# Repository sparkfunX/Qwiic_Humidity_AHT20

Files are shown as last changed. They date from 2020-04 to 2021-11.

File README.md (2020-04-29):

SparkFun Qwiic Humidity AHT20
=============================

Qwiic AHT20 (https://cdn.sparkfun.com/assets/parts/1/5/5/0/2/16618-Qwiic_Humidity_AHT20-01.jpg)

New from SparkX, the AHT20 breakout board. This low-cost IC triggers temperature and humidity measurements easily over the Qwiic bus you know and love.

SparkFun labored with love to design this board. Feel like supporting open-source hardware?
Buy a [board](https://www.sparkfun.com/) from SparkFun!

Repository Contents
-------------------

* **/Documents** - Datasheet for the AHT20 IC.
* **/Hardware** - Eagle design files (.brd, .sch).
* **/Production** - Production panel files (.brd).

License Information
-------------------

This product is _**open source**_!

Please review the LICENSE.md file for license information.

If you have any questions or concerns regarding our licensing, please contact technical support on our [SparkFun Forum](https://www.sparkfun.com/viewforum.php?f=152).

Distributed as-is; no warranty is given.

- Your friends at SparkFun

_<COLLABORATION CREDIT>_

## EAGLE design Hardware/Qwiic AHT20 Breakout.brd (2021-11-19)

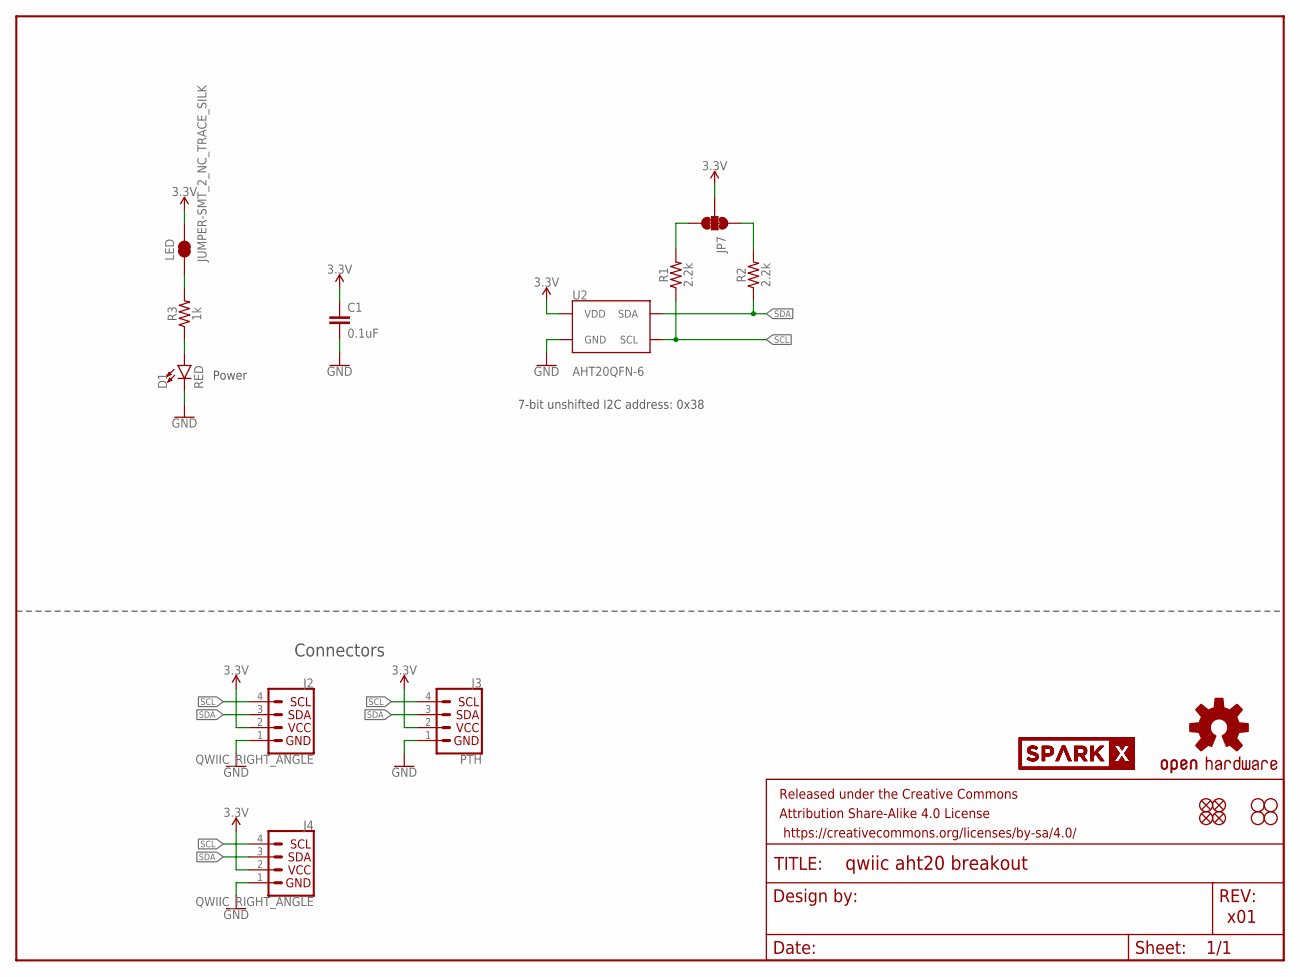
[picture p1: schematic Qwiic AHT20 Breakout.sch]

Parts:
C1: 0.1uF; 0603
D1: RED; LED-0603
FRAME1: FRAME-LETTER; CREATIVE_COMMONS
J2, J4: QWIIC_RIGHT_ANGLE; JST04_1MM_RA
J3: PTH; 1X04_NO_SILK
JP1, JP2, JP5, JP6: FIDUCIAL1X2; FIDUCIAL-1X2
JP3, JP4, JP8, JP9: STAND-OFF
JP7: JUMPER-SMT_3_2-NC_TRACE_SILK; SMT-JUMPER_3_2-NC_TRACE_SILK
LED: JUMPER-SMT_2_NC_TRACE_SILK; SMT-JUMPER_2_NC_TRACE_SILK
LOGO1: OSHW-LOGOMINI; OSHW-LOGO-MINI
R1, R2: 2.2k; 0603
R3: 1k; 0603
U2: AHT20QFN-6; QFN-6
U$1, U$2: SPARKX-LOGO4; SPARKX-MEDIUM

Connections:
3.3V: C1.1, J2.2, J3.2 (VCC), J4.2, JP7.2, LED.2, U2.VDD
GND: C1.2, D1.C, J2.1, J3.1 (GND), J4.1, U2.GND
unnamed: JP7.3, R1.2
unnamed: JP7.1, R2.2
unnamed: D1.A, R3.1
unnamed: LED.1, R3.2
SCL: J2.4, J3.4 (SCL), J4.4, R1.1, U2.SCL
SDA: J2.3, J3.3 (SDA), J4.3, R2.1, U2.SDA

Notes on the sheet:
x01
7-bit unshifted I2C address: 0x38
Power
Connectors

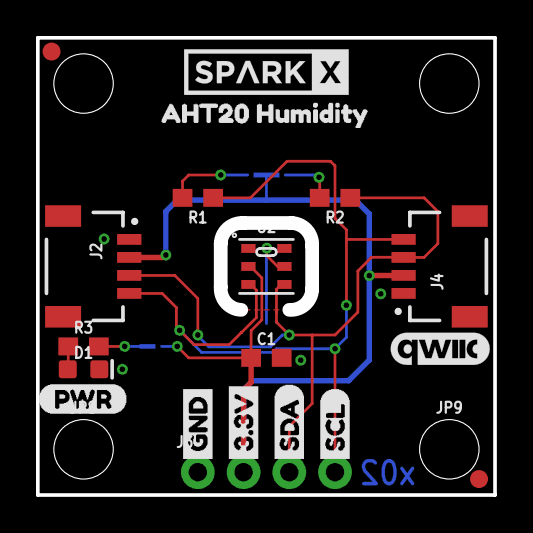
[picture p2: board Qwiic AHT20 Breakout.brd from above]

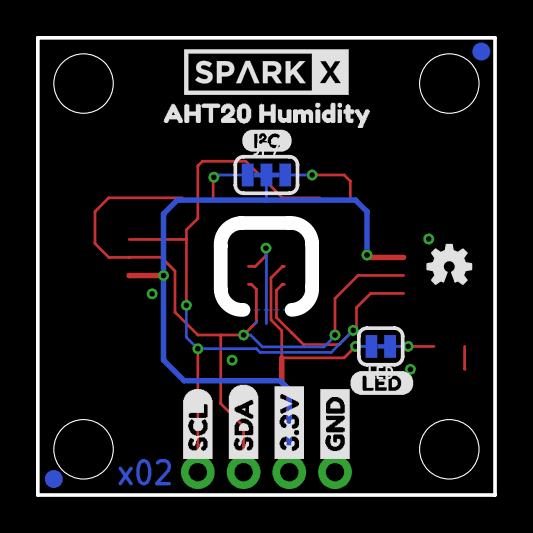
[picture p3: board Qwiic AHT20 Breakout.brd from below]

Board: 2 copper layers, 25.4 x 25.4 mm, 38 parts (13 on the bottom side), 8 nets.

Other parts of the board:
U$3, U$22: GND1
U$4, U$21: 3#3V2
U$5, U$27: SDA8
U$6, U$26: SCL9
U$8, U$14: AHT20_HUMIDITY2
U$9: I_SUPER2_C-()-03
U$10: (PWR)
U$11: QWIIC_5.5MM
U$12: LED_32
U$18: ORDERING_INSTRUCTIONS

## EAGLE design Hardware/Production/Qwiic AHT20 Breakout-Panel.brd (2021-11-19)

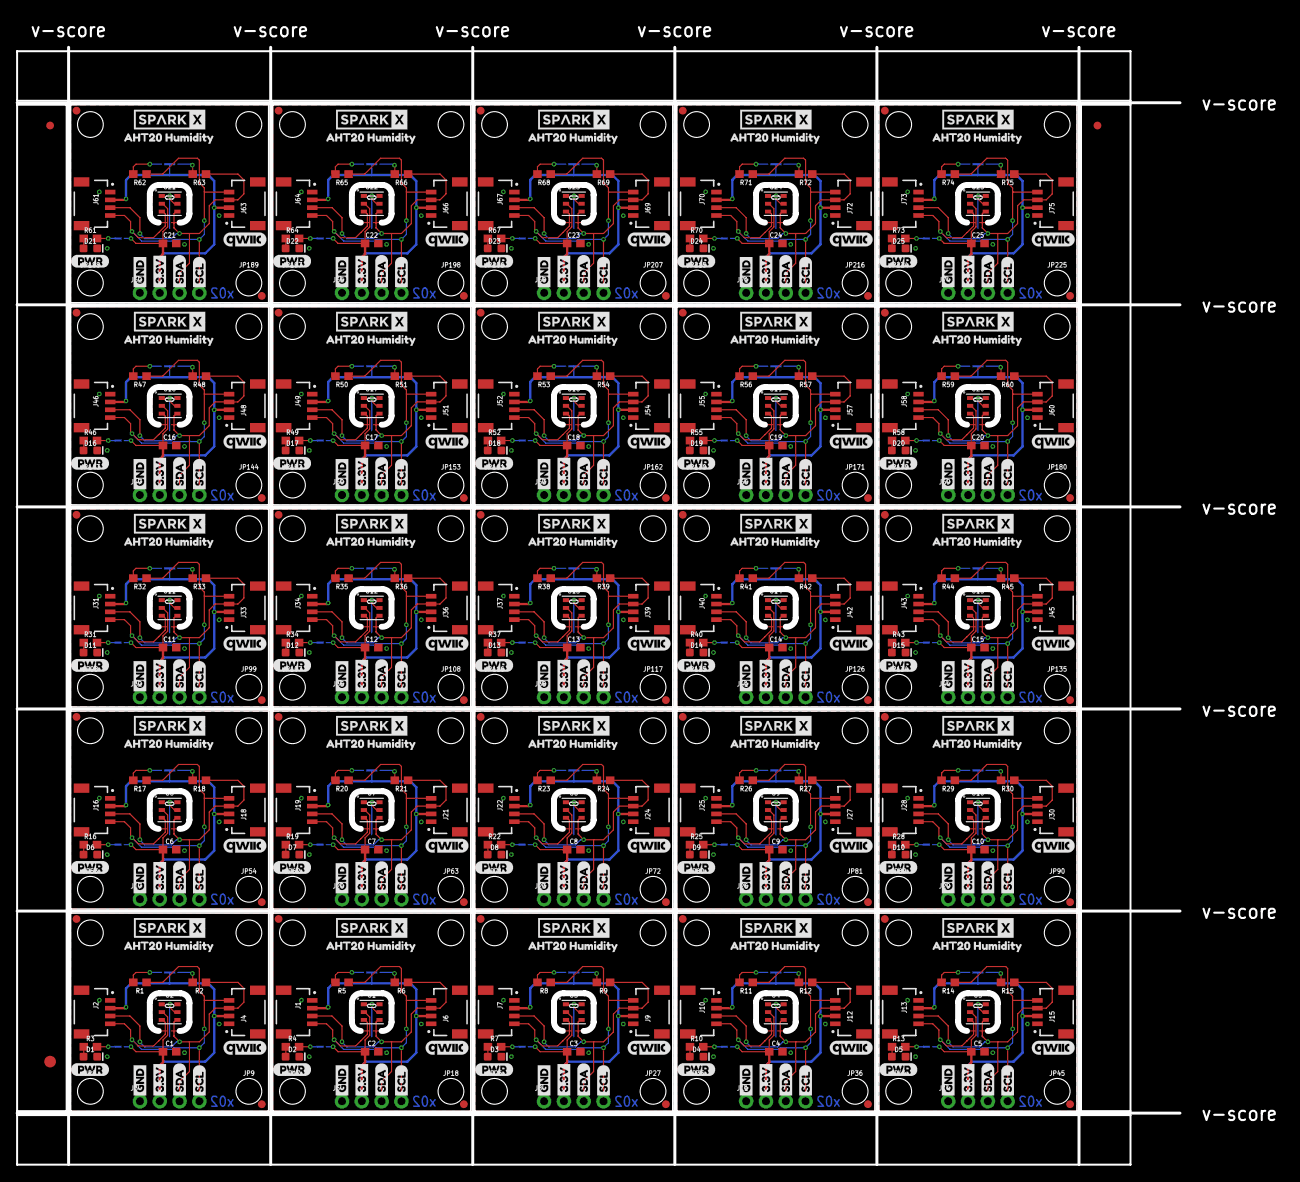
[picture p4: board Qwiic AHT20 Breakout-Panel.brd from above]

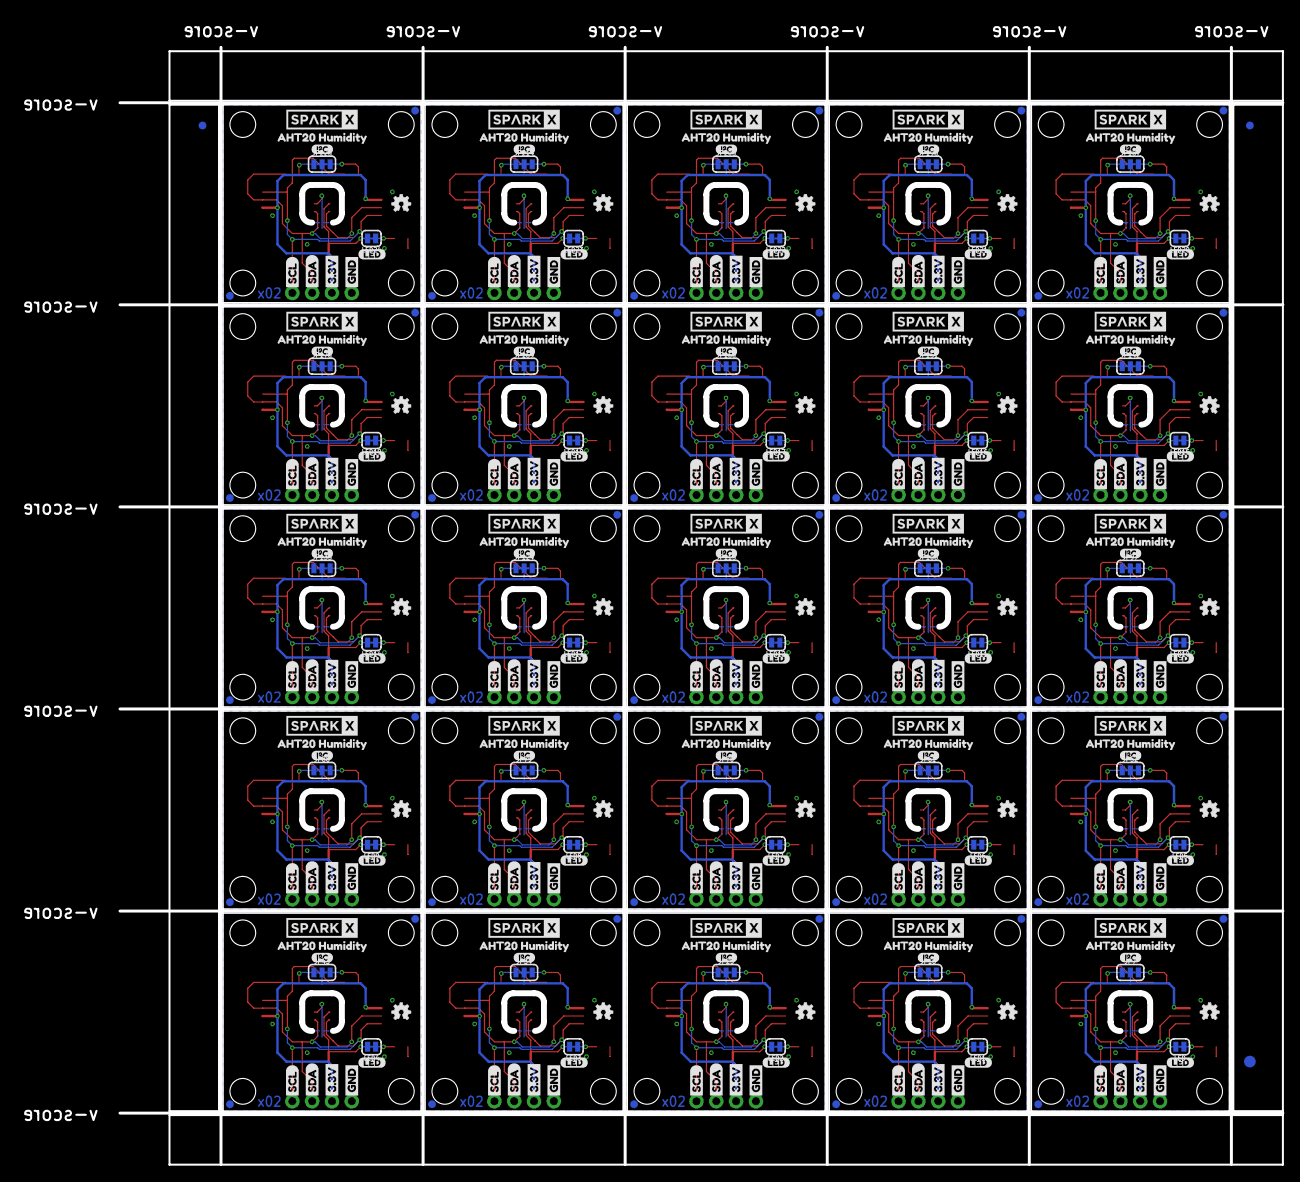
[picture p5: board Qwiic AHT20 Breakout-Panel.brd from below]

Board: 2 copper layers, 149.1 x 143.3 mm, 906 parts (328 on the bottom side), 200 nets.

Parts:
C1, C2, C3, C4, C5, C6, C7, C8, C9, C10, C11, C12, C13, C14, C15, C16, C17, C18, C19, C20, C21, C22, C23, C24, C25: 0.1uF; 0603
D1, D2, D3, D4, D5, D6, D7, D8, D9, D10, D11, D12, D13, D14, D15, D16, D17, D18, D19, D20, D21, D22, D23, D24, D25: RED; LED-0603
E$1, E$2, E$3, E$4: FIDUCIAL-1X2
E$5, E$6: FIDUCIAL-1.5X3
J1, J2, J4, J6, J7, J9, J10, J12, J13, J15, J16, J18, J19, J21, J22, J24, J25, J27, J28, J30, J31, J33, J34, J36, J37, J39, J40, J42, J43, J45, J46, J48, J49, J51, J52, J54, J55, J57, J58, J60, J61, J63, J64, J66, J67, J69, J70, J72, J73, J75: QWIIC_RIGHT_ANGLE; JST04_1MM_RA
J3, J5, J8, J11, J14, J17, J20, J23, J26, J29, J32, J35, J38, J41, J44, J47, J50, J53, J56, J59, J62, J65, J68, J71, J74: PTH; 1X04_NO_SILK
JP1, JP2, JP5, JP6, JP12, JP13, JP14, JP15, JP21, JP22, JP23, JP24, JP30, JP31, JP32, JP33, JP39, JP40, JP41, JP42, JP48, JP49, JP50, JP51, JP57, JP58, JP59, JP60, JP66, JP67, JP68, JP69, JP75, JP76, JP77, JP78, JP84, JP85, JP86, JP87, JP93, JP94, JP95, JP96, JP102, JP103, JP104, JP105, JP111, JP112, JP113, JP114, JP120, JP121, JP122, JP123, JP129, JP130, JP131, JP132, JP138, JP139, JP140, JP141, JP147, JP148, JP149, JP150, JP156, JP157, JP158, JP159, JP165, JP166, JP167, JP168, JP174, JP175, JP176, JP177, JP183, JP184, JP185, JP186, JP192, JP193, JP194, JP195, JP201, JP202, JP203, JP204, JP210, JP211, JP212, JP213, JP219, JP220, JP221, JP222: FIDUCIAL1X2; FIDUCIAL-1X2
JP3, JP4, JP8, JP9, JP10, JP11, JP17, JP18, JP19, JP20, JP26, JP27, JP28, JP29, JP35, JP36, JP37, JP38, JP44, JP45, JP46, JP47, JP53, JP54, JP55, JP56, JP62, JP63, JP64, JP65, JP71, JP72, JP73, JP74, JP80, JP81, JP82, JP83, JP89, JP90, JP91, JP92, JP98, JP99, JP100, JP101, JP107, JP108, JP109, JP110, JP116, JP117, JP118, JP119, JP125, JP126, JP127, JP128, JP134, JP135, JP136, JP137, JP143, JP144, JP145, JP146, JP152, JP153, JP154, JP155, JP161, JP162, JP163, JP164, JP170, JP171, JP172, JP173, JP179, JP180, JP181, JP182, JP188, JP189, JP190, JP191, JP197, JP198, JP199, JP200, JP206, JP207, JP208, JP209, JP215, JP216, JP217, JP218, JP224, JP225: STAND-OFF
JP7, JP16, JP25, JP34, JP43, JP52, JP61, JP70, JP79, JP88, JP97, JP106, JP115, JP124, JP133, JP142, JP151, JP160, JP169, JP178, JP187, JP196, JP205, JP214, JP223: JUMPER-SMT_3_2-NC_TRACE_SILK; SMT-JUMPER_3_2-NC_TRACE_SILK
LED, LED1, LED2, LED3, LED4, LED5, LED6, LED7, LED8, LED9, LED10, LED11, LED12, LED13, LED14, LED15, LED16, LED17, LED18, LED19, LED20, LED21, LED22, LED23, LED24: JUMPER-SMT_2_NC_TRACE_SILK; SMT-JUMPER_2_NC_TRACE_SILK
LOGO1, LOGO2, LOGO3, LOGO4, LOGO5, LOGO6, LOGO7, LOGO8, LOGO9, LOGO10, LOGO11, LOGO12, LOGO13, LOGO14, LOGO15, LOGO16, LOGO17, LOGO18, LOGO19, LOGO20, LOGO21, LOGO22, LOGO23, LOGO24, LOGO25: OSHW-LOGOMINI; OSHW-LOGO-MINI
R1, R2, R5, R6, R8, R9, R11, R12, R14, R15, R17, R18, R20, R21, R23, R24, R26, R27, R29, R30, R32, R33, R35, R36, R38, R39, R41, R42, R44, R45, R47, R48, R50, R51, R53, R54, R56, R57, R59, R60, R62, R63, R65, R66, R68, R69, R71, R72, R74, R75: 2.2k; 0603
R3, R4, R7, R10, R13, R16, R19, R22, R25, R28, R31, R34, R37, R40, R43, R46, R49, R52, R55, R58, R61, R64, R67, R70, R73: 1k; 0603
U1, U2, U3, U4, U5, U6, U7, U8, U9, U10, U11, U12, U13, U14, U15, U16, U17, U18, U19, U20, U21, U22, U23, U24, U25: AHT20QFN-6; QFN-6
U$1, U$2, U$7, U$13, U$33, U$34, U$49, U$50, U$65, U$66, U$81, U$82, U$97, U$98, U$113, U$114, U$129, U$130, U$145, U$146, U$161, U$162, U$177, U$178, U$193, U$194, U$209, U$210, U$225, U$226, U$241, U$242, U$257, U$258, U$273, U$274, U$289, U$290, U$305, U$306, U$321, U$322, U$337, U$338, U$353, U$354, U$369, U$370, U$385, U$386: SPARKX-LOGO4; SPARKX-MEDIUM
U$3, U$16, U$19, U$22, U$36, U$39, U$52, U$55, U$68, U$71, U$84, U$87, U$100, U$103, U$116, U$119, U$132, U$135, U$148, U$151, U$164, U$167, U$180, U$183, U$196, U$199, U$212, U$215, U$228, U$231, U$244, U$247, U$260, U$263, U$276, U$279, U$292, U$295, U$308, U$311, U$324, U$327, U$340, U$343, U$356, U$359, U$372, U$375, U$388, U$391: GND1
U$4, U$15, U$20, U$21, U$35, U$40, U$51, U$56, U$67, U$72, U$83, U$88, U$99, U$104, U$115, U$120, U$131, U$136, U$147, U$152, U$163, U$168, U$179, U$184, U$195, U$200, U$211, U$216, U$227, U$232, U$243, U$248, U$259, U$264, U$275, U$280, U$291, U$296, U$307, U$312, U$323, U$328, U$339, U$344, U$355, U$360, U$371, U$376, U$387, U$392: 3#3V2
U$5, U$18, U$23, U$27, U$38, U$41, U$54, U$57, U$70, U$73, U$86, U$89, U$102, U$105, U$118, U$121, U$134, U$137, U$150, U$153, U$166, U$169, U$182, U$185, U$198, U$201, U$214, U$217, U$230, U$233, U$246, U$249, U$262, U$265, U$278, U$281, U$294, U$297, U$310, U$313, U$326, U$329, U$342, U$345, U$358, U$361, U$374, U$377, U$390, U$393: SDA8
U$6, U$17, U$24, U$26, U$37, U$42, U$53, U$58, U$69, U$74, U$85, U$90, U$101, U$106, U$117, U$122, U$133, U$138, U$149, U$154, U$165, U$170, U$181, U$186, U$197, U$202, U$213, U$218, U$229, U$234, U$245, U$250, U$261, U$266, U$277, U$282, U$293, U$298, U$309, U$314, U$325, U$330, U$341, U$346, U$357, U$362, U$373, U$378, U$389, U$394: SCL9
U$8, U$14, U$30, U$32, U$46, U$48, U$62, U$64, U$78, U$80, U$94, U$96, U$110, U$112, U$126, U$128, U$142, U$144, U$158, U$160, U$174, U$176, U$190, U$192, U$206, U$208, U$222, U$224, U$238, U$240, U$254, U$256, U$270, U$272, U$286, U$288, U$302, U$304, U$318, U$320, U$334, U$336, U$350, U$352, U$366, U$368, U$382, U$384, U$398, U$400: AHT20_HUMIDITY2
U$9, U$28, U$44, U$60, U$76, U$92, U$108, U$124, U$140, U$156, U$172, U$188, U$204, U$220, U$236, U$252, U$268, U$284, U$300, U$316, U$332, U$348, U$364, U$380, U$396: I_SUPER2_C-()-03
U$10, U$25, U$43, U$59, U$75, U$91, U$107, U$123, U$139, U$155, U$171, U$187, U$203, U$219, U$235, U$251, U$267, U$283, U$299, U$315, U$331, U$347, U$363, U$379, U$395: (PWR)
U$11, U$29, U$45, U$61, U$77, U$93, U$109, U$125, U$141, U$157, U$173, U$189, U$205, U$221, U$237, U$253, U$269, U$285, U$301, U$317, U$333, U$349, U$365, U$381, U$397: QWIIC_5.5MM
U$12, U$31, U$47, U$63, U$79, U$95, U$111, U$127, U$143, U$159, U$175, U$191, U$207, U$223, U$239, U$255, U$271, U$287, U$303, U$319, U$335, U$351, U$367, U$383, U$399: LED_32

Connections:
3.3V: C1.1, J2.2, J3.2, J4.2, JP7.2, LED.2, U2.VDD
3.3V1: C2.1, J1.2, J5.2, J6.2, JP16.2, LED1.2, U1.VDD
3.3V2: C3.1, J7.2, J8.2, J9.2, JP25.2, LED2.2, U3.VDD
3.3V3: C4.1, J10.2, J11.2, J12.2, JP34.2, LED3.2, U4.VDD
3.3V4: C5.1, J13.2, J14.2, J15.2, JP43.2, LED4.2, U5.VDD
3.3V5: C6.1, J16.2, J17.2, J18.2, JP52.2, LED5.2, U6.VDD
3.3V6: C7.1, J19.2, J20.2, J21.2, JP61.2, LED6.2, U7.VDD
3.3V7: C8.1, J22.2, J23.2, J24.2, JP70.2, LED7.2, U8.VDD
3.3V8: C9.1, J25.2, J26.2, J27.2, JP79.2, LED8.2, U9.VDD
3.3V9: C10.1, J28.2, J29.2, J30.2, JP88.2, LED9.2, U10.VDD
3.3V10: C11.1, J31.2, J32.2, J33.2, JP97.2, LED10.2, U11.VDD
3.3V11: C12.1, J34.2, J35.2, J36.2, JP106.2, LED11.2, U12.VDD
3.3V12: C13.1, J37.2, J38.2, J39.2, JP115.2, LED12.2, U13.VDD
3.3V13: C14.1, J40.2, J41.2, J42.2, JP124.2, LED13.2, U14.VDD
3.3V14: C15.1, J43.2, J44.2, J45.2, JP133.2, LED14.2, U15.VDD
3.3V15: C16.1, J46.2, J47.2, J48.2, JP142.2, LED15.2, U16.VDD
3.3V16: C17.1, J49.2, J50.2, J51.2, JP151.2, LED16.2, U17.VDD
3.3V17: C18.1, J52.2, J53.2, J54.2, JP160.2, LED17.2, U18.VDD
3.3V18: C19.1, J55.2, J56.2, J57.2, JP169.2, LED18.2, U19.VDD
3.3V19: C20.1, J58.2, J59.2, J60.2, JP178.2, LED19.2, U20.VDD
3.3V20: C21.1, J61.2, J62.2, J63.2, JP187.2, LED20.2, U21.VDD
3.3V21: C22.1, J64.2, J65.2, J66.2, JP196.2, LED21.2, U22.VDD
3.3V22: C23.1, J67.2, J68.2, J69.2, JP205.2, LED22.2, U23.VDD
3.3V23: C24.1, J70.2, J71.2, J72.2, JP214.2, LED23.2, U24.VDD
3.3V24: C25.1, J73.2, J74.2, J75.2, JP223.2, LED24.2, U25.VDD
GND: C1.2, D1.C, J2.1, J3.1, J4.1, U2.GND
GND1: C2.2, D2.C, J1.1, J5.1, J6.1, U1.GND
GND2: C3.2, D3.C, J7.1, J8.1, J9.1, U3.GND
GND3: C4.2, D4.C, J10.1, J11.1, J12.1, U4.GND
GND4: C5.2, D5.C, J13.1, J14.1, J15.1, U5.GND
GND5: C6.2, D6.C, J16.1, J17.1, J18.1, U6.GND
GND6: C7.2, D7.C, J19.1, J20.1, J21.1, U7.GND
GND7: C8.2, D8.C, J22.1, J23.1, J24.1, U8.GND
GND8: C9.2, D9.C, J25.1, J26.1, J27.1, U9.GND
GND9: C10.2, D10.C, J28.1, J29.1, J30.1, U10.GND
GND10: C11.2, D11.C, J31.1, J32.1, J33.1, U11.GND
GND11: C12.2, D12.C, J34.1, J35.1, J36.1, U12.GND
GND12: C13.2, D13.C, J37.1, J38.1, J39.1, U13.GND
GND13: C14.2, D14.C, J40.1, J41.1, J42.1, U14.GND
GND14: C15.2, D15.C, J43.1, J44.1, J45.1, U15.GND
GND15: C16.2, D16.C, J46.1, J47.1, J48.1, U16.GND
GND16: C17.2, D17.C, J49.1, J50.1, J51.1, U17.GND
GND17: C18.2, D18.C, J52.1, J53.1, J54.1, U18.GND
GND18: C19.2, D19.C, J55.1, J56.1, J57.1, U19.GND
GND19: C20.2, D20.C, J58.1, J59.1, J60.1, U20.GND
GND20: C21.2, D21.C, J61.1, J62.1, J63.1, U21.GND
GND21: C22.2, D22.C, J64.1, J65.1, J66.1, U22.GND
GND22: C23.2, D23.C, J67.1, J68.1, J69.1, U23.GND
GND23: C24.2, D24.C, J70.1, J71.1, J72.1, U24.GND
GND24: C25.2, D25.C, J73.1, J74.1, J75.1, U25.GND
unnamed: JP7.3, R1.2
unnamed: JP7.1, R2.2
unnamed: D1.A, R3.1
unnamed: LED.1, R3.2
unnamed: D2.A, R4.1
unnamed: JP16.3, R5.2
unnamed: JP16.1, R6.2
unnamed: LED1.1, R4.2
unnamed: D3.A, R7.1
unnamed: JP25.3, R8.2
unnamed: JP25.1, R9.2
unnamed: LED2.1, R7.2
unnamed: D4.A, R10.1
unnamed: JP34.3, R11.2
unnamed: JP34.1, R12.2
unnamed: LED3.1, R10.2
unnamed: D5.A, R13.1
unnamed: JP43.3, R14.2
unnamed: JP43.1, R15.2
unnamed: LED4.1, R13.2
unnamed: D6.A, R16.1
unnamed: JP52.3, R17.2
unnamed: JP52.1, R18.2
unnamed: LED5.1, R16.2
unnamed: D7.A, R19.1
unnamed: JP61.3, R20.2
unnamed: JP61.1, R21.2
unnamed: LED6.1, R19.2
unnamed: D8.A, R22.1
unnamed: JP70.3, R23.2
unnamed: JP70.1, R24.2
unnamed: LED7.1, R22.2
unnamed: D9.A, R25.1
unnamed: JP79.3, R26.2
unnamed: JP79.1, R27.2
unnamed: LED8.1, R25.2
unnamed: D10.A, R28.1
unnamed: JP88.3, R29.2
unnamed: JP88.1, R30.2
unnamed: LED9.1, R28.2
unnamed: D11.A, R31.1
unnamed: JP97.3, R32.2
unnamed: JP97.1, R33.2
unnamed: LED10.1, R31.2
unnamed: D12.A, R34.1
unnamed: JP106.3, R35.2
unnamed: JP106.1, R36.2
unnamed: LED11.1, R34.2
unnamed: D13.A, R37.1
unnamed: JP115.3, R38.2
unnamed: JP115.1, R39.2
unnamed: LED12.1, R37.2
unnamed: D14.A, R40.1
unnamed: JP124.3, R41.2
unnamed: JP124.1, R42.2
unnamed: LED13.1, R40.2
unnamed: D15.A, R43.1
unnamed: JP133.3, R44.2
unnamed: JP133.1, R45.2
unnamed: LED14.1, R43.2
unnamed: D16.A, R46.1
unnamed: JP142.3, R47.2
unnamed: JP142.1, R48.2
unnamed: LED15.1, R46.2
unnamed: D17.A, R49.1
unnamed: JP151.3, R50.2
unnamed: JP151.1, R51.2
unnamed: LED16.1, R49.2
unnamed: D18.A, R52.1
unnamed: JP160.3, R53.2
unnamed: JP160.1, R54.2
unnamed: LED17.1, R52.2
unnamed: D19.A, R55.1
unnamed: JP169.3, R56.2
unnamed: JP169.1, R57.2
unnamed: LED18.1, R55.2
unnamed: D20.A, R58.1
unnamed: JP178.3, R59.2
unnamed: JP178.1, R60.2
unnamed: LED19.1, R58.2
unnamed: D21.A, R61.1
unnamed: JP187.3, R62.2
unnamed: JP187.1, R63.2
unnamed: LED20.1, R61.2
unnamed: D22.A, R64.1
unnamed: JP196.3, R65.2
unnamed: JP196.1, R66.2
unnamed: LED21.1, R64.2
unnamed: D23.A, R67.1
unnamed: JP205.3, R68.2
unnamed: JP205.1, R69.2
unnamed: LED22.1, R67.2
unnamed: D24.A, R70.1
unnamed: JP214.3, R71.2
unnamed: JP214.1, R72.2
unnamed: LED23.1, R70.2
unnamed: D25.A, R73.1
unnamed: JP223.3, R74.2
unnamed: JP223.1, R75.2
unnamed: LED24.1, R73.2
SCL: J2.4, J3.4, J4.4, R1.1, U2.SCL
SCL1: J1.4, J5.4, J6.4, R5.1, U1.SCL
SCL2: J7.4, J8.4, J9.4, R8.1, U3.SCL
SCL3: J10.4, J11.4, J12.4, R11.1, U4.SCL
SCL4: J13.4, J14.4, J15.4, R14.1, U5.SCL
SCL5: J16.4, J17.4, J18.4, R17.1, U6.SCL
SCL6: J19.4, J20.4, J21.4, R20.1, U7.SCL
SCL7: J22.4, J23.4, J24.4, R23.1, U8.SCL
SCL8: J25.4, J26.4, J27.4, R26.1, U9.SCL
SCL9: J28.4, J29.4, J30.4, R29.1, U10.SCL
SCL10: J31.4, J32.4, J33.4, R32.1, U11.SCL
SCL11: J34.4, J35.4, J36.4, R35.1, U12.SCL
SCL12: J37.4, J38.4, J39.4, R38.1, U13.SCL
SCL13: J40.4, J41.4, J42.4, R41.1, U14.SCL
SCL14: J43.4, J44.4, J45.4, R44.1, U15.SCL
SCL15: J46.4, J47.4, J48.4, R47.1, U16.SCL
SCL16: J49.4, J50.4, J51.4, R50.1, U17.SCL
SCL17: J52.4, J53.4, J54.4, R53.1, U18.SCL
SCL18: J55.4, J56.4, J57.4, R56.1, U19.SCL
SCL19: J58.4, J59.4, J60.4, R59.1, U20.SCL
SCL20: J61.4, J62.4, J63.4, R62.1, U21.SCL
SCL21: J64.4, J65.4, J66.4, R65.1, U22.SCL
SCL22: J67.4, J68.4, J69.4, R68.1, U23.SCL
SCL23: J70.4, J71.4, J72.4, R71.1, U24.SCL
SCL24: J73.4, J74.4, J75.4, R74.1, U25.SCL
SDA: J2.3, J3.3, J4.3, R2.1, U2.SDA
SDA1: J1.3, J5.3, J6.3, R6.1, U1.SDA
SDA2: J7.3, J8.3, J9.3, R9.1, U3.SDA
SDA3: J10.3, J11.3, J12.3, R12.1, U4.SDA
SDA4: J13.3, J14.3, J15.3, R15.1, U5.SDA
SDA5: J16.3, J17.3, J18.3, R18.1, U6.SDA
SDA6: J19.3, J20.3, J21.3, R21.1, U7.SDA
SDA7: J22.3, J23.3, J24.3, R24.1, U8.SDA
SDA8: J25.3, J26.3, J27.3, R27.1, U9.SDA
SDA9: J28.3, J29.3, J30.3, R30.1, U10.SDA
SDA10: J31.3, J32.3, J33.3, R33.1, U11.SDA
SDA11: J34.3, J35.3, J36.3, R36.1, U12.SDA
SDA12: J37.3, J38.3, J39.3, R39.1, U13.SDA
SDA13: J40.3, J41.3, J42.3, R42.1, U14.SDA
SDA14: J43.3, J44.3, J45.3, R45.1, U15.SDA
SDA15: J46.3, J47.3, J48.3, R48.1, U16.SDA
SDA16: J49.3, J50.3, J51.3, R51.1, U17.SDA
SDA17: J52.3, J53.3, J54.3, R54.1, U18.SDA
SDA18: J55.3, J56.3, J57.3, R57.1, U19.SDA
SDA19: J58.3, J59.3, J60.3, R60.1, U20.SDA
SDA20: J61.3, J62.3, J63.3, R63.1, U21.SDA
SDA21: J64.3, J65.3, J66.3, R66.1, U22.SDA
SDA22: J67.3, J68.3, J69.3, R69.1, U23.SDA
SDA23: J70.3, J71.3, J72.3, R72.1, U24.SDA
SDA24: J73.3, J74.3, J75.3, R75.1, U25.SDA

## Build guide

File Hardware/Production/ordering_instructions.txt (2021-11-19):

panel size, 143x143mm
PCB thickness, 0.8mm
number of layers, 2
soldermask color, Black
silkscreen color, White
oz copper, 1oz
finish, HASL lead free
stencils, none
pcs per panel, 25
min trace width, 0.1524mm / 0.0060in
min drill size, 0.3048mm / 0.0120in

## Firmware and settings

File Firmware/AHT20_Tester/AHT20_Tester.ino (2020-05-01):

/*

*/
#include <Wire.h>

#include <SparkFun_Qwiic_Humidity_AHT20.h> //Click here to get the library: http://librarymanager/All#Qwiic_Humidity_AHT20 by SparkFun
AHT20 humiditySensor;

#define STAT_LED 13

void setup()
{
  Serial.begin(115200);
  Serial.println("Qwiic Humidity AHT20 examples");

  pinMode(STAT_LED, OUTPUT);
  digitalWrite(STAT_LED, LOW);

  Wire.begin();
}

void loop()
{
  //Check if the AHT20 will acknowledge
  if (humiditySensor.begin() == true)
  {
    while (1)
    {
      //If a new measurement is available
      if (humiditySensor.available() == true)
      {
        //Get the new temperature and humidity value
        float temperature = humiditySensor.getTemperature();
        float humidity = humiditySensor.getHumidity();

        Serial.print(humidity, 2);
        Serial.print("% ");
        Serial.print(temperature, 2);
        Serial.print("C");

        if (temperature > 22 && temperature < 30 && humidity > 5 && humidity < 80)
        {
          digitalWrite(STAT_LED, HIGH);
          Serial.print(" Good!");
        }

        Serial.println();
      }

      delay(50);

      if (humiditySensor.begin() == false) break;
    }
  }
  else
  {
    Serial.println("AHT20 not detected. Please check wiring. Freezing.");
    digitalWrite(STAT_LED, LOW);
  }
  delay(50);

}

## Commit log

2020-04-13 Got HW example working with brand new HW
    Fixed I2C write/read sequence
    Added debugging print statements
2020-04-29 Correct spacing to 2mm on FP.
2020-04-29 Fix FP of IC to correct 2mm pad spacing
    [Qwiic AHT20 Breakout.brd, Qwiic AHT20 Breakout.sch]
2020-05-01 Fix FP spacing. Remove experimental ADR feature. Update version number.
    [Qwiic AHT20 Breakout-Panel.brd, Qwiic AHT20 Breakout.brd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]
2020-05-04 Update Qwiic AHT20 Breakout.pdf
    Removed file path comment from bottom of schematic
2021-11-19 Add x02 panel.
    [Qwiic AHT20 Breakout-Panel.brd, Qwiic AHT20 Breakout.brd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]

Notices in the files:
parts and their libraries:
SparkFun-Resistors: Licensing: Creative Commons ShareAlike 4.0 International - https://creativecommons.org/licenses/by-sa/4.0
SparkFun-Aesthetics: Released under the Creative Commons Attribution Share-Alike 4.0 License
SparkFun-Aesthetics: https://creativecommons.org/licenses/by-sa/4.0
